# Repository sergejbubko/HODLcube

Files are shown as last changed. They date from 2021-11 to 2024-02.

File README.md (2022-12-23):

# HODLcube 
Cryptocurrency ticker connected to Coinbase [Buy on Etsy](https://etsy.me/3WgRvl4)

[Quick Start Guide](https://docs.google.com/document/d/1Tg4MM1jNnUUqZixxY0ZYTSoNqewVLtktd7ysAPqDA4k/edit?usp=sharing) can be found on Google Docs and
[video](https://youtu.be/ECuRcL1aRUg) can be found on Youtube



### List of parts
- **Wemos D1 mini V3.0** ([link](https://www.aliexpress.com/item/32831353752.html)) or newer **Lolin D1 mini V3.1.0** ([link](https://www.aliexpress.com/item/32529101036.html)). Original version with big silver plate and FCC logo on it won't fit!

Inkedd1mini_LI

- OLED 1.3" 128x64 display ([link](https://www.aliexpress.com/item/32683094040.html))
- active 5V buzzer ([link](https://www.aliexpress.com/item/4001112067716.html))
- 1 pc green LED 5 mm ([link](https://www.aliexpress.com/item/33015212696.html))
- 1 pc red LED 5 mm
- 1 pc 15R resistor 0.25 W ([link](https://www.aliexpress.com/item/32922643786.html)) for green LED; resistance may vary, see specifications of your LED
- 1 pc 51R resistor 0.25 W for red LED; resistance may vary, see specifications of your LED. You can use a calculator like [this](https://www.digikey.com/en/resources/conversion-calculators/conversion-calculator-led-series-resistor)

- female to female dupont cables ([link](https://www.aliexpress.com/item/1699285992.html))
- 28AWG wires ([link](https://www.aliexpress.com/item/4001178609999.html)) 24AWG - 28AWG should be fine, using colours depends on you. You can also reuse dupont cables with removed connectors
- self-tapping screws with (optional) collar
  - 2 pcs 2.3x4 mm ([link](https://www.aliexpress.com/item/1005001508219065.html))
  - 2 pcs 2x6 mm
- piece of PCB, with 6x14 holes - cut PCB size 20x80mm with 6x28 holes in half with shears or bench shear ([link](https://www.aliexpress.com/item/1005002011006453.html))

### You will also need
- 3D printer ([link](https://www.aliexpress.com/item/1005002378407440.html))
- PLA and/or PETG filaments ([link](https://www.aliexpress.com/item/32957585470.html))
- soldering iron ([link](https://www.aliexpress.com/item/32903921345.html))
- solder
- patience

### 3D printing
Parts are free to download on [thingiverse](https://www.thingiverse.com/thing:5031142)
1. Print the top part of the HODLcube from white translucent filament. [White PETG from Sunlu](https://www.aliexpress.com/item/32957585470.html) is recommended. It depends on your experience. This part has to be translucent but don't have to be transparent. LED light have to go through easily.
2. Print the rest five parts from PLA/PETG filament with colour of your choice


### Soldering
*see scheme for cable lenghts and colours*
1. Solder LEDs and resistors on top of cutted 6x14 PCB

     
3. Solder buzzer and all wires on the other side of PCB


5. All negatives (buzzer, resistors and also display GND dupont cable should lead to one spot with negative wire leading to GND of D1 mini)
6. Now solder all wires (positive green LED, positive red LED, positive buzzer, common negative wire) from this PCB to holes in D1 mini board
7. Solder 4 Dupont male cables for display


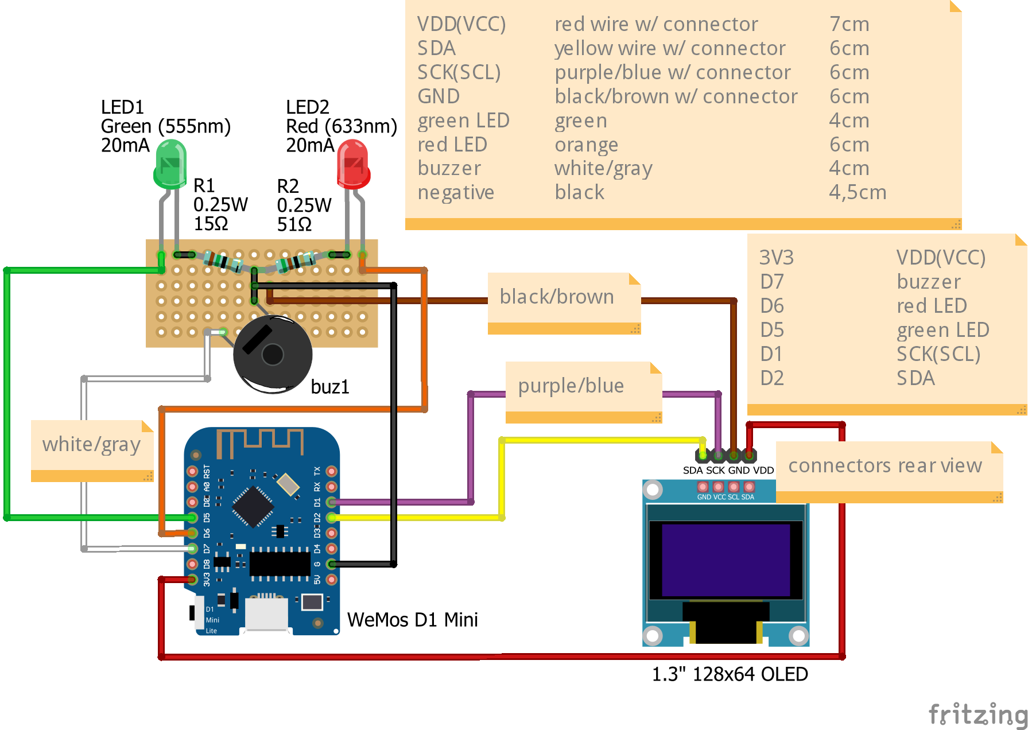
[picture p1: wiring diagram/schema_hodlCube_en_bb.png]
schema_hodlCube_en_bb


### Test
1. Connect Dupont cables to display (see scheme)
2. Double check correct wiring
3. Connect D1 mini using micro USB cable to PC
4. Download
   - .bin file from [releases](https://github.com/sergejbubko/HODLcube/releases) and use esptool to flash it or visit this [page](https://nerdiy.de/en/howto-esp8266-mit-dem-esptool-bin-dateien-unter-windows-flashen/) for more information about esptool and its alternative with GUI called [ESPEasyFlasher](https://github.com/BattloXX/ESPEasyFlasher)
   - OR .zip file of this project and using [Arduino IDE](https://www.arduino.cc/en/software) compile it and upload to D1 mini, nice tutorial can be found [here](https://randomnerdtutorials.com/how-to-install-esp8266-board-arduino-ide/). In Arduino IDE > Tools don't forget to check that you have selected:
     - correct board in Board > ESP8266 boards > **LOLIN(WEMOS) D1 R2 & mini**.
     - **115200** upload speed 
     
     You also need to include all libraries. You should find them in Library Manager in Arduino IDE or collect them manualy by downloading neccessary archives from github. Links are provided in sourcecode HODLcube.ino next to each included library.

### Assembly
1. Push the LEDs into top 3D printed part. For correct orientation see image below.


2. Put the D1 mini board onto bottom part and use two smaller screws to catch it on place
3. The display should snap on front part, use two bigger screws on upper part


4. Now put left, bottom, top and right part together. If it doesn't fit well use sharp knife or sandpaper. The reset button on D1 mini should face the small hole in left part.
5. Snap on the front part. If it is too hard to snap it in use drill bit and adjust holes for the pins.
6. Connect all 4 wires to display and snap in tha back part.



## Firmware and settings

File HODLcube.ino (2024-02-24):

/*******************************************************************
    A project to display crypto currency prices using an ESP8266

    Main Hardware:
    - Lolin D1 mini (Any ESP8266 dev board will work)
    - OLED I2C 1.3" Display (SH1106)

 *******************************************************************/

// ----------------------------
// Standard Libraries - Already Installed if you have ESP8266 set up
// ----------------------------

#include <WiFiClientSecure.h>
#include <Wire.h>

// ----------------------------
// Additional Libraries - each one of these will need to be installed.
// ----------------------------

#include "CoinbaseApi.h"

#include "webStrings.h"
#include "graphic_oledi2c.h"

#include "SH1106.h"
// The driver for the OLED display
// Available on the library manager (Search for "oled ssd1306")
// https://github.com/ThingPulse/esp8266-oled-ssd1306

// https://github.com/bblanchon/ArduinoJson
#include <ArduinoJson.h>
// Available on the library manager (Search for "arduino json")

#include <Arduino.h>
#include <ESP8266WiFi.h>
// this fork is necessary https://github.com/taranais/NTPClient
#include <NTPClient.h>
#include <WiFiUdp.h>
// https://github.com/me-no-dev/ESPAsyncTCP
#include <ESPAsyncTCP.h>
#include <Hash.h>
#include <FS.h>
// https://github.com/me-no-dev/ESPAsyncWebServer
#include <ESPAsyncWebServer.h>

#include <strings_en.h>
// https://github.com/tzapu/WiFiManager/tree/feature_asyncwebserver
#include <WiFiManager.h>        

// https://github.com/datacute/DoubleResetDetector
#include <DoubleResetDetector.h>

// Pins based on your wiring
// display
#define SCL_PIN D1
#define SDA_PIN D2

// LEDs
#define GREEN_LED D5
#define RED_LED D6

// Buzzer
#define BUZZER_PIN D7

// Display power
#define DISPLAY_POWER_PIN D8

// Have tested up to 5, can probably do more
#define MAX_HOLDINGS 5

// number of crypto showing in config portal
#define PAIRS_COUNT 16

// Number of seconds after reset during which a 
// subseqent reset will be considered a double reset.
#define DRD_TIMEOUT 10

// RTC Memory Address for the DoubleResetDetector to use
#define DRD_ADDRESS 0

// Time intervals in millis
#define MINUTE_INTERVAL 60000
#define HOUR_INTERVAL 3600000
#define DAY_INTERVAL 86400000

const char* VER = "v0.5.2";

struct Holding {
  String tickerId;
  float newPrice;
  float oldPrice;
  bool inUse;
  unsigned long statsReadDue;
  unsigned long weekAgoPriceReadDue;
  unsigned long YTDPriceReadDue;
  CBPTickerResponse lastTickerResponse;
  CBPStatsResponse lastStatsResponse;
  CBPCandlesResponse weekAgoPriceResponse;
  CBPCandlesResponse YTDPriceResponse;
  float priceCheckpoint;
};

struct Settings {
  float LEDtickThresh; // LED threshold for two prices in a row (ticker) in percent
  float buzzTickThresh; // buzzer threshold for two prices in a row (ticker) in percent
  float buzzCPThresh; // buzzer threshold for difference between checkpoint price and current price in percent
// We'll request a new value just before we change the screen so it's the most up to date
// Rate Limits: https://docs.cloud.coinbase.com/exchange/docs/rate-limits
// We throttle public endpoints by IP: 10 requests per second, up to 15 requests per second in bursts. Some endpoints may have custom rate limits.
  unsigned long screenChangeDelay; // milis
  String pairs[MAX_HOLDINGS];
};

char ssidAP[] = "HODLcube";  // SSID of the device
char pwdAP[] = "toTheMoon";  // password of the device

unsigned long screenChangeDue = 0;
unsigned long checkDateTimeInterval = 0;

int dataNotLoadedCounter = 0;

String dateWeekAgo = "";
String currentYear = "";
const char *filename = "/settings.txt";
Settings settings;                         // <- global settings object
int currentIndex = -1;

AsyncWebServer server(80);
WiFiClientSecure clientSSL;
CoinbaseApi api(clientSSL);
DoubleResetDetector drd(DRD_TIMEOUT, DRD_ADDRESS);
Holding holdings[MAX_HOLDINGS];

SH1106 display(0x3c, SDA_PIN, SCL_PIN);

// Define NTP Client to get time
WiFiUDP ntpUDP;
NTPClient timeClient(ntpUDP, "pool.ntp.org");

// Loads the settings from a file
void loadSettings(const char *filename, Settings &settings) {
  // Open file for reading
  File file = SPIFFS.open(filename, "r");
  if (!file) {
    Serial.println(F("ERR: Failed to read file, using default values"));
    settings.LEDtickThresh = 0.01;
    // threshold for difference of last two loaded prices in a row in percent
    settings.buzzTickThresh = 0.01; 
    // threshold for daily price change in percent
    settings.buzzCPThresh = 5.0;
    // time in milis to reload new prices and/or another pair from list
    settings.screenChangeDelay = 5000;  
    // list of cryptocurrencies to choose from
    settings.pairs[0] = String("BTC-USD"); 
    settings.pairs[1] = String("null"); 
    settings.pairs[2] = String("null"); 
    settings.pairs[3] = String("null"); 
    settings.pairs[4] = String("null"); 
    return;
  }

  // Allocate a temporary JsonDocument
  // Don't forget to change the capacity to match your requirements.
  // Use www.arduinojson.org/v6/assistant to compute the capacity.
  StaticJsonDocument<768> doc;

  // Deserialize the JSON document
  DeserializationError error = deserializeJson(doc, file);
  if (error) {
    Serial.print(F("ERR: Failed to deserialize json - "));
    Serial.println(error.f_str());
  }

  // Copy values from the JsonDocument to the Config
  // threshold for difference of last two loaded prices in a row in percent
  settings.LEDtickThresh = doc["LEDtickThresh"] | 0.01;
  // threshold for difference of last two loaded prices in a row in percent
  settings.buzzTickThresh = doc["buzzTickThresh"] | 0.01; 
  // threshold for daily price change in percent
  settings.buzzCPThresh = doc["buzzCPThresh"] | 5.0;
  // time in milis to reload new prices and/or another pair from list
  settings.screenChangeDelay = doc["screenChangeDelay"] | 5000;  
  // list of cryptocurrencies to choose from
  settings.pairs[0] = String(doc["pair0"] | "BTC-USD");  
  for (int i = 1; i < MAX_HOLDINGS; i++) {
    settings.pairs[i] = String(doc["pair" + String(i)]);  
  }
  
// Close the file
  file.close();
}

// Saves the settings to a file
void saveSettings(const char *filename, const Settings &settings) {
  // Delete existing file, otherwise the settings is appended to the file
  SPIFFS.remove(filename);

  // Open file for writing
  File file = SPIFFS.open(filename, "w");
  if (!file) {
    Serial.println(F("ERR: Failed to create file"));
    return;
  }

  // Allocate a temporary JsonDocument
  // Don't forget to change the capacity to match your requirements.
  // Use www.arduinojson.org/assistant to compute the capacity.
  StaticJsonDocument<512> doc;
  
  // Set the values in the document 
  doc["LEDtickThresh"] = settings.LEDtickThresh;
  doc["buzzTickThresh"] = settings.buzzTickThresh;
  doc["buzzCPThresh"] = settings.buzzCPThresh;
  doc["screenChangeDelay"] = settings.screenChangeDelay;  
  for (int i = 0; i < MAX_HOLDINGS; i++) {
    doc["pair" + String(i)] = settings.pairs[i];
  } 
  
  // Serialize JSON to file
  if (serializeJson(doc, file) == 0) {
    Serial.println(F("ERR: Failed to serialize json to file"));
  }
  // Close the file
  file.close();
}

// Loads the settings from a file
float loadCheckpointPrice(String filename) {
  // Open file for reading
  File file = SPIFFS.open(filename, "r");
  if (!file) {
    Serial.print(F("ERR: Failed to read file - "));
    Serial.println(filename);
    return 0.0;
  }

  float fileContent;
  while(file.available()){
    fileContent = file.parseFloat();
  }
  
// Close the file
  file.close();
  return fileContent;
}

// Saves the settings to a file
void saveCheckpointPrice(String filename, const float price) {
  // Delete existing file, otherwise the settings is appended to the file
  SPIFFS.remove(filename);

  // Open file for writing
  File file = SPIFFS.open(filename, "w");
  if (!file) {
    Serial.println(F("ERR. Failed to create file"));
    return;
  }

  if(!file.print(price)){
    Serial.print(F("ERR. File write failed: "));
    Serial.println(file.name());
  } else {
    Serial.print(F("New checkpoint saved to file "));
    Serial.print(file.name());
    Serial.print("-> ");
    Serial.println(price);
  }
  // Close the file
  file.close();
}

// Prints the content of a file to the Serial
void printFile(const char *filename) {
  // Open file for reading
  File file = SPIFFS.open(filename, "r");
  if (!file) {
    Serial.println(F("ERR: Failed to read file"));
    return;
  }

  // Extract each characters by one by one
  while (file.available()) {
    Serial.print((char)file.read());
  }
  Serial.println();

  // Close the file
  file.close();
}

void notFound(AsyncWebServerRequest *request) {
  request->send(404, "text/plain", "Not found");
}

// Replaces placeholder with stored values
// it looks for variables in format %var_name%
String processor(const String& var){
  //Serial.println(var);
  if(var == "INPUT_LED_TICK_THRESH"){
    return String(settings.LEDtickThresh);
  }
  if(var == "INPUT_BUZZ_TICK_THRESH"){
    return String(settings.buzzTickThresh);
  }
  if(var == "INPUT_BUZZ_CP_THRESH"){
    return String(settings.buzzCPThresh);
  }
  if(var == "SCREEN_CHANGE_DELAY" + String(settings.screenChangeDelay)){
     return "selected";
  }
  if(var == "CURRENCY_PAIRS") {
    String result = "";
    for (int i = 0; i < MAX_HOLDINGS; i++) {
      result += "'" + settings.pairs[i] + "',";
    }
    return result;
  }
  if (var == "CURRENCY_CHECKPOINTS") {
    String result;
    result.reserve(1200);
    for (int i = 0; i < MAX_HOLDINGS; i++) {
      if (holdings[i].inUse && holdings[i].priceCheckpoint >= 0.1) {
         result +=
         "<div class='mb-2'>"
            "<label for='chkp_" + holdings[i].tickerId + "' class='col-form-label'>" + holdings[i].tickerId + "</label>"
            "<div class='mb-2'>"
              "<input type='number' name='chkp_" + holdings[i].tickerId + "' step='0.01' min='0.01' value='" + String(holdings[i].priceCheckpoint) + "' class='form-control' required>"
            "</div>"
          "</div>";
      }
    }
    return result;
  }
  return String();
}

void addNewHolding(String &tickerId, float newPrice = 0, float oldPrice = 0) {
  int index = getNextFreeHoldingIndex();
  if (index > -1) {
    holdings[index].tickerId = tickerId;
    holdings[index].newPrice = newPrice;
    holdings[index].oldPrice = oldPrice;
    holdings[index].inUse = true;
    holdings[index].statsReadDue = 0;
    holdings[index].weekAgoPriceReadDue = 0;
    holdings[index].priceCheckpoint = loadCheckpointPrice("/" + tickerId + ".txt");
  }
}

void configModeCallback (WiFiManager *myWiFiManager) {
  Serial.println(F("Entered config mode"));
  Serial.println(WiFi.softAPIP());

  Serial.println(myWiFiManager->getConfigPortalSSID());
  
  display.clear();
  display.setTextAlignment(TEXT_ALIGN_LEFT);
  display.setFont(ArialMT_Plain_10);
  display.drawStringMaxWidth(0, 0, 128, F("Use phone/PC and connect to wifi SSID:"));
  display.setFont(ArialMT_Plain_16);
  display.drawString(5, 22, ssidAP);
  display.setFont(ArialMT_Plain_10);
  display.drawString(0, 37, F("password:"));
  display.setFont(ArialMT_Plain_16);
  display.drawString(5, 48, pwdAP);
  display.display();
}

void setup() {
  WiFi.mode(WIFI_STA); // explicitly set mode, esp defaults to STA+AP
  Serial.begin(115200);
  while (!Serial) continue;
  pinMode(RED_LED, OUTPUT);
  pinMode(GREEN_LED, OUTPUT);
  pinMode(BUZZER_PIN, OUTPUT);

  // Initialising the display
  display.init();
  display.flipScreenVertically();
  display.setTextAlignment(TEXT_ALIGN_CENTER);

  display.clear();
  display.drawXbm(27, 5, MAINLOGO_WIDTH, MAINLOGO_HEIGHT, mainLogo);
  display.setTextAlignment(TEXT_ALIGN_RIGHT);
  display.setFont(ArialMT_Plain_10);
  display.drawString(128, 54, VER);
  display.display();
  //delay(2000);

  //WiFiManager
  //Local intialization. Once its business is done, there is no need to keep it around
  WiFiManager wm;  
  //reset saved settings - testing purpose
  //wm.resetSettings();
  //fetches ssid and pass from eeprom and tries to connect
  //if it does not connect it starts an access point with the specified name

  std::vector<const char *> menu = {
    "wifi",
    "info",
    "restart",
    "exit"};
  wm.setMenu(menu);
  wm.setAPCallback(configModeCallback);
  if (drd.detectDoubleReset()) {
    Serial.println(F("Double Reset Detected"));
    wm.setConfigPortalTimeout(120);

    if (!wm.startConfigPortal(ssidAP, pwdAP)) {
      displayMessage("Failed to connect and hit timeout. Reseting in 5 secs.");
      delay(5000);
      //reset and try again, or maybe put it to deep sleep
      ESP.restart();
    }
  } else {
    Serial.println(F("No Double Reset Detected"));
    if (wm.autoConnect(ssidAP, pwdAP)) {
      Serial.println(F("connected...yeey :)"));
    } else {
      displayMessage("Connection error. No AP set. Will restart in 10 secs. Follow instructions on screen and set network credentials.");
      delay(10000);
      ESP.restart();
    }
  }   

  // Initialize SPIFFS
  if(!SPIFFS.begin()){
    Serial.println(F("An Error has occurred while mounting SPIFFS"));
    return;
  }

  // Should load default config if run for the first time
  Serial.println(F("Loading settings..."));
  loadSettings(filename, settings);

  // Create settings file
  Serial.println(F("Saving settings..."));
  saveSettings(filename, settings);

  // Dump config file
  Serial.println(F("Print config file..."));
  printFile(filename);

  for (int i = 0; i < MAX_HOLDINGS; i++) {
    if (settings.pairs[i] != "null") {
      Serial.print(F("Added #"));
      Serial.print(i);
      Serial.print(F(":"));
      Serial.println(settings.pairs[i]);
      addNewHolding(settings.pairs[i]);
    }
  }
  IPAddress ip = WiFi.localIP();
//  Serial.println(ip);

  display.clear();
  display.setTextAlignment(TEXT_ALIGN_CENTER);
  display.setFont(ArialMT_Plain_16);
  display.drawString(64, 4, F("Browse to"));
  display.drawString(64, 22, ip.toString());
  display.drawString(64, 40, F("for config"));
  display.display();
  //ipAddressString = ip.toString();

  // Send web page with input fields to client
  server.on("/", HTTP_GET, [](AsyncWebServerRequest *request){
    request->send_P(200, "text/html", index_html, processor);
  });

  // Send a GET request to <ESP_IP>/get?inputString=<inputMessage>
  server.on("/get", HTTP_GET, [] (AsyncWebServerRequest *request) {
    // GET inputLEDtickThresh value on <ESP_IP>/get?inputLEDtickThresh=<inputMessage>
    int params = request->params();
    int j = 0;
    for(int i=0;i<params;i++) {
      AsyncWebParameter* p = request->getParam(i);
      if (p->name() == "inputLEDtickThresh") {
        settings.LEDtickThresh = p->value().toFloat();
      } else if (p->name() == "inputBuzzTickThresh") {
        settings.buzzTickThresh = p->value().toFloat();
      } else if (p->name() == "inputBuzzCPThresh") {
        settings.buzzCPThresh = p->value().toFloat();
      } else if (p->name() == "inputScreenChangeDelay") {
        settings.screenChangeDelay = (long)p->value().toInt();
      } else if (p->name() == "inputCurrencyPairs") {
        if (j < MAX_HOLDINGS) {
          settings.pairs[j] = p->value();
          j++;
        }
      } else if (p->name().startsWith("chkp_")) {
        for (int i = 0; i < MAX_HOLDINGS; i++) {
          if (holdings[i].inUse && p->name() == "chkp_" + holdings[i].tickerId &&
          fabs(holdings[i].priceCheckpoint - p->value().toFloat()) >= 0.01) {
            Serial.println(holdings[i].priceCheckpoint, 10);
            Serial.println(p->value().toFloat(), 10);
            holdings[i].priceCheckpoint = p->value().toFloat();   
            saveCheckpointPrice("/" + holdings[i].tickerId + ".txt", holdings[i].priceCheckpoint);
          }
        }
      }
    }
    // reset other values
    while(j < MAX_HOLDINGS) {
      settings.pairs[j] = "null";
      j++;
    }
    Serial.println(F("Saving configuration..."));
    saveSettings(filename, settings);
    
    // Dump config file
    Serial.println(F("Print config file..."));
    printFile(filename);
    
    request->send(200);
    ESP.restart();
  });
  server.onNotFound(notFound);
  server.begin();
  
  // Initialize a NTPClient to get time
  timeClient.begin();
  // Set offset time in seconds to adjust for your timezone, for example:
  // GMT +1 = 3600
  // GMT +8 = 28800
  // GMT -1 = -3600
  // GMT 0 = 0
  timeClient.setTimeOffset(0);
  
  delay(2000);
}

int getNextFreeHoldingIndex() {
  for (int i = 0; i < MAX_HOLDINGS; i++) {
    if (!holdings[i].inUse) {
      return i;
    }
  }

  return -1;
}

int getNextIndex() {
  for (int i = currentIndex + 1; i < MAX_HOLDINGS; i++) {
    if (holdings[i].inUse) {
      return i;
    }
  }

  for (int j = 0; j <= currentIndex; j++) {
    if (holdings[j].inUse) {
      return j;
    }
  }

  return -1;
}

void displayHolding(int index) {

  CBPTickerResponse tickerResponse = holdings[index].lastTickerResponse;
  CBPStatsResponse statsResponse = holdings[index].lastStatsResponse;

  display.clear();
  display.setTextAlignment(TEXT_ALIGN_CENTER);
  display.setFont(ArialMT_Plain_16);
  String tickerId = holdings[index].tickerId;
  tickerId.toUpperCase();
  // c++ char formatting using +/- sign
  char percent_change_24h[6];
  snprintf(percent_change_24h, sizeof(percent_change_24h), "%+3.1f", (tickerResponse.price / statsResponse.open - 1) * 100);
  display.drawString(64, 0, tickerId + " " + percent_change_24h + "%");
  display.setFont(ArialMT_Plain_24);
  float price = (float)tickerResponse.price;
  holdings[index].oldPrice = holdings[index].newPrice;
  holdings[index].newPrice = price;
  display.drawString(64, 20, formatCurrency(price));
  display.setTextAlignment(TEXT_ALIGN_LEFT);
  display.setFont(ArialMT_Plain_10);
  display.drawString(2, 45, F("L:"));
  display.drawString(15, 45, formatCurrency(statsResponse.low));  
  display.drawString(2, 54, F("H:"));
  display.drawString(15, 54, formatCurrency(statsResponse.high));
  // c++ char formatting using +/- sign
  char percent_change_7d[8] = "N/A";
  if (holdings[index].weekAgoPriceResponse.open) {
    snprintf(percent_change_7d, sizeof(percent_change_7d), "%+3.1f", (tickerResponse.price / holdings[index].weekAgoPriceResponse.open - 1) * 100);
  }
  display.drawString(55, 45, F("7d: "));
  display.drawString(82, 45, String(percent_change_7d) + "%");
  // c++ char formatting using +/- sign
  char percent_change_YTD[8] = "N/A";
  if (holdings[index].YTDPriceResponse.open) {
    snprintf(percent_change_YTD, sizeof(percent_change_YTD), "%+3.1f", (tickerResponse.price / holdings[index].YTDPriceResponse.open - 1) * 100);
  }
  display.drawString(55, 54, F("YTD: "));
  display.drawString(82, 54, String(percent_change_YTD) + "%");
 
  if (holdings[index].newPrice < holdings[index].oldPrice) {
    display.fillTriangle(110, 29, 124, 29, 117, 36);
  } else if (holdings[index].newPrice > holdings[index].oldPrice) {
    display.fillTriangle(110, 37, 124, 37, 117, 30);
  }
  display.display();
  if (holdings[index].newPrice < (holdings[index].oldPrice * (1.0 - settings.LEDtickThresh / 100.0))) {
    LEDdown();
  }
  else if (holdings[index].newPrice > (holdings[index].oldPrice * (1.0 + settings.LEDtickThresh / 100.0)) && holdings[index].oldPrice != 0) {
    LEDup();
  }
  if (holdings[index].newPrice < (holdings[index].oldPrice * (1.0 - settings.buzzTickThresh / 100.0))) {
    buzzerDown();
  }
  else if (holdings[index].newPrice > (holdings[index].oldPrice * (1.0 + settings.buzzTickThresh / 100.0)) && holdings[index].oldPrice != 0) {
    buzzerUp();
  }  
  float priceTrend = isCPThreshReached(index);
  if (priceTrend != 0.0) {
    buzzer(priceTrend, index);
  }
}

void LEDdown(){    
  // Flash LED
  digitalWrite(RED_LED, HIGH);
  delay(50);
  digitalWrite(RED_LED, LOW);
}
void LEDup(){    
  // Flash LED
  digitalWrite(GREEN_LED, HIGH);
  delay(50);
  digitalWrite(GREEN_LED, LOW); 
}
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
void loop() {

  // so that it can recognise when the timeout expires.
  // You can also call drd.stop() when you wish to no longer
  // consider the next reset as a double reset.
  drd.loop();

  unsigned long timeNow = millis();
  if (timeNow > checkDateTimeInterval) {
    updateDate();    
    // check date and time every hour
    checkDateTimeInterval = timeNow + HOUR_INTERVAL;
  }
  if ((timeNow > screenChangeDue))  {    
    currentIndex = getNextIndex();
    if (currentIndex > -1) {
//      Serial.print("Current holding index: ");
//      Serial.println(currentIndex);
      if (loadDataForHolding(currentIndex, timeNow)) {
        displayHolding(currentIndex);
        dataNotLoadedCounter = 0;
      } else {
        dataNotLoadedCounter++;
        Serial.print(F("Number of data loading errors in a row: "));
        Serial.println(dataNotLoadedCounter);
      }
      if (dataNotLoadedCounter > 5) {
        displayMessage("Error loading data. Check wifi connection or increase screen change delay in config.");
      }
      if (dataNotLoadedCounter > 20) {
        ESP.restart();
      }
    } else {
      displayMessage("No funds to display. Edit the setup to add them");
    }
    screenChangeDue = timeNow + settings.screenChangeDelay;
  }
}

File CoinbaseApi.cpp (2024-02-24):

#include "CoinbaseApi.h"

CoinbaseApi::CoinbaseApi(WiFiClientSecure &client)  {
  this->client = &client;
  responseTickerObject = CBPTickerResponse();
  responseStatsObject = CBPStatsResponse();
  responseCandlesObject = CBPCandlesResponse();
}

String CoinbaseApi::SendGetToCoinbase(String &command) {
  String body="";
  body.reserve(700);
  bool finishedHeaders = false;
  bool currentLineIsBlank = true;
  long now;
  bool avail;
  int i;
  int j;
  
  client->setInsecure();
  if (client->connect(COINBASE_HOST, Port)) {
    // Serial.println(".... connected to server");
    char c;
    int ch_count=0;
    client->println("GET " + command + " HTTP/1.1");
    client->println("Host: " COINBASE_HOST);
    client->println(F("User-Agent: arduino/1.0.0"));
    client->println();
    now=millis();
    avail=false;
    while (millis()-now<1500) {
      while (client->available()) {
        char c = client->read();
        // Serial.write(c);

        if(!finishedHeaders){
          if (currentLineIsBlank && c == '\n') {
            finishedHeaders = true;
          }
        } else {
          body=body+c;
          ch_count++;
        }

        if (c == '\n') {
          currentLineIsBlank = true;
        }else if (c != '\r') {
          currentLineIsBlank = false;
        }

        avail=true;
      }
      if (avail) {
//         Serial.println("Body:");
//         Serial.println(body);
//         Serial.println("END");
        break;
      }
    }
    // search for left curly braces or square brackets
    for (i = 0; i < ch_count; i++) {
      if (body.charAt(i) == '{' || body.charAt(i) == '[') {
        break;
      }
    }
    // search for right curly braces or square brackets
    for (j = ch_count; j > i; j--) {
      if (body.charAt(j) == '}' || body.charAt(j) == ']') {
        break;
      }   
    }
  }
  closeClient();  
  return body.substring(i, j+1);
}

CBPTickerResponse CoinbaseApi::GetTickerInfo(String &tickerId) {
  
  // https://api.exchange.coinbase.com/products/btc-eur/ticker  
  String commandTicker="/products/" + tickerId + "/ticker";
  
  String responseTicker = SendGetToCoinbase(commandTicker);
  Serial.print(tickerId); 
  Serial.print(F(" ticker: "));
  Serial.println(responseTicker);
  
  StaticJsonDocument<384> ticker;
  
  // Deserialize the JSON document
  DeserializationError errorTicker = deserializeJson(ticker, responseTicker);
  
  // Test if parsing succeeds.
  if (errorTicker) {
    responseTickerObject.error = errorTicker.f_str();
//    Serial.print(F("deserializeJson() failed: "));
//    Serial.println(errorTicker.f_str());
    return responseTickerObject;
  }

  // Fetch values
//    /ticker: {"trade_id":41905060,"price":"47892.67","size":"0.00201603","time":"2021-05-05T16:52:24.740835Z","bid":"47885.33","ask":"47892.67","volume":"2016.48486351"}
  responseTickerObject.price = ticker["price"].as<float>();
  responseTickerObject.error = "";

  return responseTickerObject;
}

CBPStatsResponse CoinbaseApi::GetStatsInfo(String &tickerId) {

  // https://api.exchange.coinbase.com/products/btc-eur/stats
  String commandStats="/products/" + tickerId + "/stats";
  
  String responseStats = SendGetToCoinbase(commandStats);
  Serial.print(tickerId);
  Serial.print(" stats: ");
  Serial.println(responseStats);
  
  StaticJsonDocument<512> stats;
  
  // Deserialize the JSON document
  DeserializationError errorStats = deserializeJson(stats, responseStats);

  // Test if parsing succeeds.
  if (errorStats) {
    responseStatsObject.error = errorStats.f_str();
//    Serial.print(F("deserializeJson() failed: "));
//    Serial.println(errorStats.f_str());
    return responseStatsObject;
  }

  // Fetch values
  //    /stats: {"open":"40680","high":"40789.98","low":"36445","volume":"3771.22613578","last":"39082.37","volume_30day":"102943.0112141"}
  responseStatsObject.open = stats["open"].as<float>();
  responseStatsObject.high = stats["high"].as<float>();
  responseStatsObject.low = stats["low"].as<float>();
  responseStatsObject.error = "";
 
  return responseStatsObject;
}

CBPCandlesResponse CoinbaseApi::GetCandlesInfo(String &tickerId, String &date) {
  // https://api.exchange.coinbase.com/products/btc-eur/candles?granularity=86400&start=2021-01-01&end=2021-01-01
  String commandCandles="/products/" + tickerId + "/candles?granularity=86400&start=" + date + "&end=" + date;
  
  String responseCandles = SendGetToCoinbase(commandCandles);
  Serial.print(tickerId);
  Serial.print(F(" candles "));
  Serial.print(date);
  Serial.print(F(": "));
  Serial.println(responseCandles);

  StaticJsonDocument<256> candles;

  // Deserialize the JSON document
  DeserializationError errorCandles = deserializeJson(candles, responseCandles);  

  // Test if parsing succeeds.
  if (errorCandles) {
    responseCandlesObject.error = errorCandles.f_str();
//    Serial.print(F("deserializeJson() failed: "));
//    Serial.println(errorCandles.f_str());
    return responseCandlesObject;
  }

  // Fetch values
  // [[1609459200,23512.7,24250,23706.73,24070.97,1830.04655405]]
  responseCandlesObject.open = candles[0][3].as<float>();
  responseCandlesObject.error = "";
 
  return responseCandlesObject;
}

void CoinbaseApi::closeClient() {
  if(client->connected()){
    client->stop();
  }
}

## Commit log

2021-05-05 Battery testing, Ticker from Coinbase
    - testing battery, showing voltage on display
    - adding Product Ticker from Coinbase Pro enables updating price more often
2021-05-09 Battery protection and battery level
    Put ESP to deep sleep mode if battery voltage drops below 3.4 V.
    Added battery level icons.
2021-05-13 low battery bug fix, api read optimization
2021-05-30 Bug fix, OTA updates
    [HODLcube.ino]
2021-08-06 Crypto selection fix
    Unchecking selected crypto pairs wasn't saved properly into json.
    [HODLcube.ino]
2021-08-28 added 30day volume, rearranged text, bug fix
    [HODLcube.ino]
2021-10-07 -buzzer threshold logic redesigned -buzzer sound changes -web UI settings redesigned
    [HODLcube.ino]
2021-10-17 - TODO - this commit is not working version -- added 7d stats and YTD stats - not completed -- reading current time from ntp
    [HODLcube.ino]
2021-10-20 - now showing 7d stats and YTD stats correctly
    [HODLcube.ino]
2021-10-28 - bug fix - buzzer, LEDs timing and behaviour has changed - added display price alert on long term price watcher
    [HODLcube.ino]
2021-11-03 - revert checkbox input changes from previous commit - checkpoint prices are now stored in persistant memory - not affected by device restart
    [HODLcube.ino]
2021-11-04 - redesigned selection of currency pairs, now using all available pairs loaded from coinbase api -> it will probably be necessary to check the display limits - html page for settings moved to SPIFFS 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
    [HODLcube.ino]
2021-11-18 - price checkpoints as input fields - need to check performance issues when loaded all 5 fields
    [HODLcube.ino]
2021-11-30 - memory allocation fix - added some serial output - disabled edit option for price checkpoints lower or equal than 0.1 - prevent saving new checkpoint values if not changed
    [HODLcube.ino]
2021-11-30 - added svg logo for cut graphics - added Fritzing wiring diagram
    [schema_hodlCube_en.fzz]
2023-01-12 - added auto restart after 20 errors of data loading
    [HODLcube.ino]
2023-03-30 - clean response from API by deleting all extra characters before and after brackets
